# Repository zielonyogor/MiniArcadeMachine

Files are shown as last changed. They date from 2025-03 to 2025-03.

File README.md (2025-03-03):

# Mini-Arcade-Machine
Project made for Embedded Systems laboratories at Poznań University of Technology.

## General Information
This project is a miniature gaming machine inspired by arcade machines from the 1980s. It supports three types of logic games:
* Minesweeper, 
* Memory,
* Simon Says.  

The machine utilizes a Raspberry Pi 4B along with a PiTFT touchscreen. Case model was designed using FreeCAD and 3D-printed. It is controlled via a joystick and buttons. Additionally, a built-in buzzer produces sounds and plays melodies.  

For more information check out our (polish) [documentation](doc/project_report.pdf).

## Setup guide 

To setup the PiTFT display, refer to the official PiTFT [documentation](https://cdn-learn.adafruit.com/downloads/pdf/adafruit-pitft-28-inch-resistive-touchscreen-display-raspberry-pi.pdf).  
After that install pygame along with sdl library using the following command:

* *sudo apt install python3-pygame libsdl2-dev*

After successful installation run the program using:

* *sudo python main.py*

## Project presentation
To see our arcade machine in action look at the project showcase [video](doc/project_showcase.mp4).  

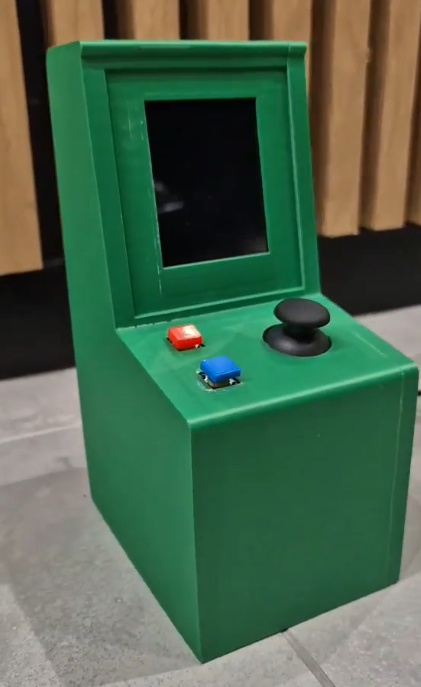
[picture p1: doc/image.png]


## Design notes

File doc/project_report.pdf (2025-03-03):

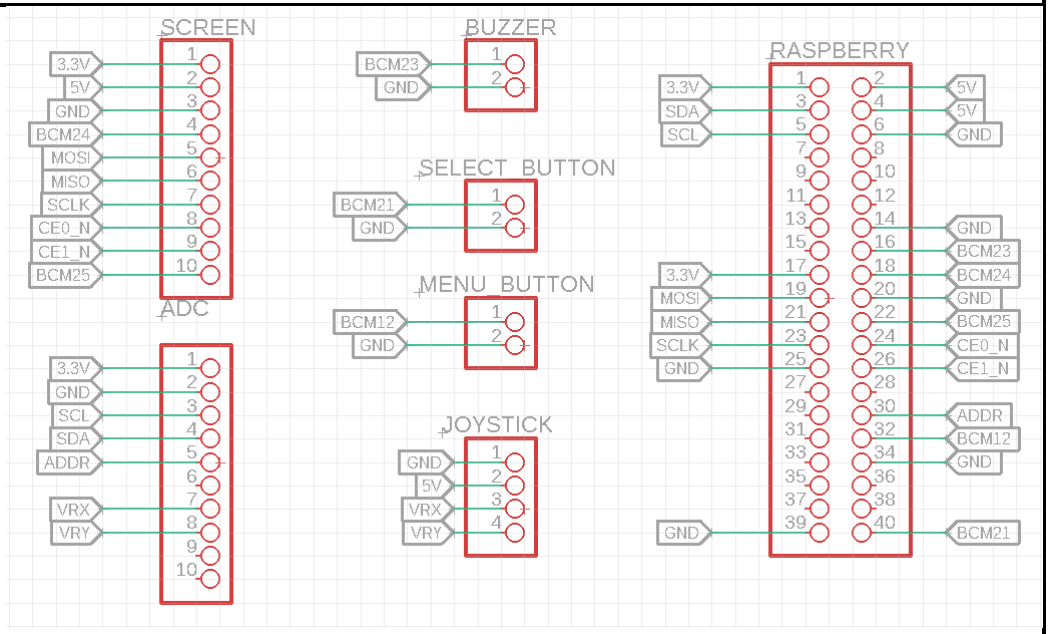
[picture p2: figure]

1

[Z7] KARTA PROJEKTU

Grupa laboratoryjna: L10/L4

Prowadzący zajęcia:

Mini Arcade Machine

CEL PROJEKTU

Stworzenie miniaturowej maszyny do gier inspirowanej maszynami arkadowymi z lat 80’. Maszyna posiada 3 rodzaje gier logicznych: Minesweeper, Memory oraz Simon Says. Model maszyny jest wydrukowany w drukarce 3D. Maszyna posiada joystick i 2 przyciski. Wbudowany jest również buzzer wydający efekty dźwiękowe oraz grający melodię.

SCHEMAT POGLĄDOWY (UPROSZCZONY)

WYKORZYSTANA
PLATFORMA
SPRZĘTOWA, ELEMENTY
POMIAROWE
I WYKONAWCZE

Raspberry Pi 4B, Thumb Joystick, przyciski Tact Switch, buzzer pasywny, wyświetlacz LCD TFT

2

1. Cel i zakres projektu.

Celem projektu było stworzenie miniaturowej maszyny do gier, inspirowanej maszynami arkadowymi z lat 80’. W wydrukowanej na drukarce 3D ‘maszynie’ znajduje się Raspberry Pi 4B, do której podłączone są urządzenia wyjścia oraz wejścia, takie jak: joystick, przyciski, buzzer, wyświetlacz. Całość zasilana jest za pomocą dedykowanego zasilacza USB C dla Raspberry Pi 4B.
Maszyna posiada 3 gry: „Minesweeper”, „Simon Says”, „Match-2” oraz tabele najlepszych wyników dla każdej z gier. Minesweeper, czyli saper to gra, której celem jest znalezienie bomb rozłożonych na planszy. Jako wskazówka, co do położenia bomb, reszta kafelek na planszy posiada liczbę, odpowiadającą liczbie bomb w sąsiedztwie danego kafelka. Im szybciej gracz odkryje wszystkie kafelki niezawierające bomb, tym lepszy wynik osiągnie. „Simon Says” to gra na czas, której celem jest odegranie melodii, naśladując podświetlone kafelki. Wynik liczony jest na podstawie ilości odegranych nut. „Match-2” to gra polegająca na zapamiętywaniu położenia kafelków odpowiedniego koloru oraz połączeniu dwóch kafelków o tych samych kolorach. Wynik jest liczony na podstawie czasu, ile graczowi zajęło połączenie wszystkich kolorów. Gry zostały napisane w języku programowania Python z użyciem biblioteki PyGame. PyGame jest prostą biblioteką stworzoną z myślą o tworzeniu gier w języku Python. Do przechowywania wyników użyliśmy bazy danych w SQLite. Pomimo małego rozmiaru przechowywanych wyników, zdecydowaliśmy się na użycie SQLite ze względu na prostotę zapytań i obsługi danych w porównaniu z tak zwaną „hardcodowaną” obsługą danych w pliku ‘txt’. Do interakcji z grą służą: joystick – do akcji „lewo”, „prawo”, „góra” i „dół” oraz dwa przyciski – niebieski – akcja „zatwierdź”, czerwony – akcja „menu”. Buzzer został wykorzystany jako informacja zwrotna dla gracza. W zależności od akcji, jaką gracz wykona, buzzer zagra krótką melodię: radosną, sugerującą wygraną grę lub smutną, sugerującą koniec gry. Dodatkowo buzzer reaguje krótkim dźwiękiem podczas wciskania przycisku interakcji.
Maszyna posiada w menu gry opcję bezpiecznego wyłączenia. Należy użyć tej opcji przed odłączeniem od zasilania, aby zabezpieczyć system przed korupcją plików.

Wykorzystany sprzęt:
- Raspberry Pi 4B 4GB RAM
- Wyświetlacz TFT 2.8”
- Thumb Joystick
- Konwerter ADC ADS1115
- Przyciski Tact Switch - x2
- Buzzer pasywny
- Zasilacz USB C 5.1V/3A do Raspberry Pi
- Przewody połączeniowe

Wykorzystane oprogramowanie:
- Visual Studio Code – programowanie i prototypowanie logiki gier
- PyCharm Proffesional Edition – komunikacja i przesyłanie oprogramowania do Raspberry Pi 4B
- FreeCAD – modelowanie 3D obudowy

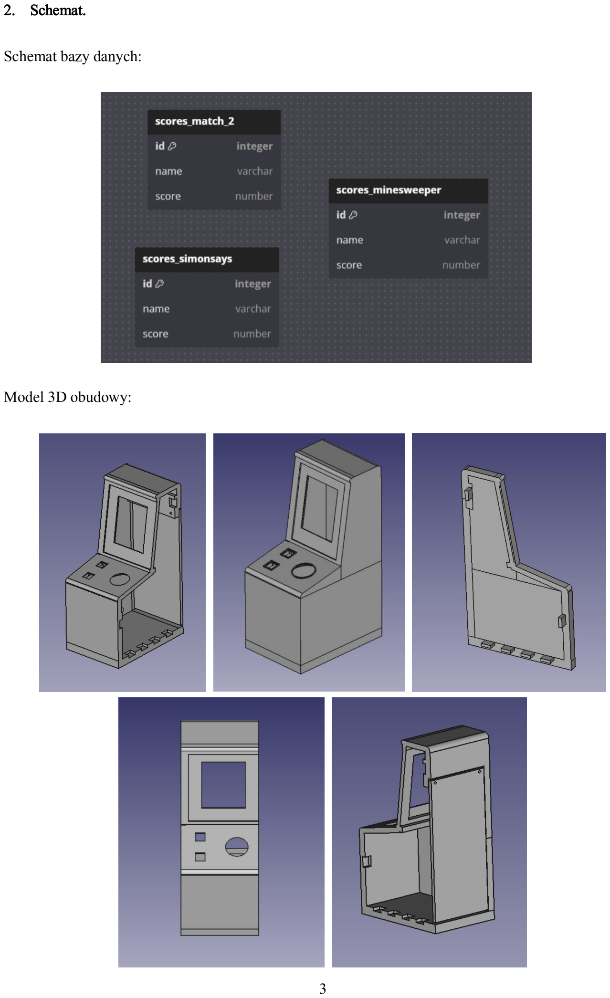
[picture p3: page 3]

3

2. Schemat.

Schemat bazy danych:

Model 3D obudowy:

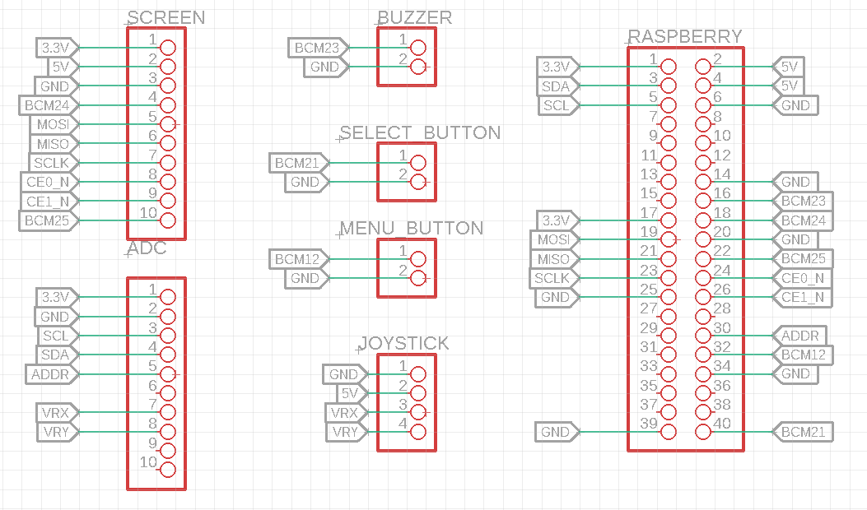
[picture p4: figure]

4

Schemat połączeniowy:

3. Zał oż enia projektowe a ich realizacja.

W założeniach projektowych planowaliśmy użyć przenośnego zasilania w postaci koszyka na akumulatory, jednakże ze względu na czas, jaki mogliśmy przeznaczyć na projekt oraz ryzyko jakie mogło nieść ze sobą zasilanie o niepewnym poziomie napięcia (ze względu na rozładowanie, np. możliwość błędnego odczytu wartości na joysticku przy operowaniu na niższym poziomie napięcia) postanowiliśmy stworzyć naszą maszynę bardziej zbliżoną oryginałom i uzależnić jej działanie od dostępu do gniazdka. Sprzęt zasilany jest poprzez dedykowaną do Raspberry Pi 4 ładowarkę USB-C.
Planowaliśmy również zaprojektować płytkę PCB do naszego projektu, jednak po dłuższym rozważeniu tej opcji uznaliśmy, że nie jest opłacalne poświęcać czas i pieniądze na dedykowaną płytkę, jako że cały nasz układ udało się połączyć zwykłymi przewodami z Raspberry Pi 4 w roli płytki PCB.
Projekt ma ogromne możliwości dalszego rozwoju. Nasz obecny projekt zajmuje niewielką frakcję obecnej pamięci, zostawiając sporo miejsca na możliwe przyszłe gry. Kombinacja joysticka i towarzyszących mu dwóch przycisków pozwala na przeróżne implementacje gier. Obecna implementacja reaguje wyłącznie na ruchy joysticka w kierunkach prawo/lewo/góra/dół. Można to zmienić w kodzie, aby pozwolić na odczyt pełnego zakresu ruchów joysticka, odkrywając nowe możliwe gry, czy techniki do wykorzystania w implementacji.

5

4. Listing kodu.

# Fragment pliku input.py zawierający obsługę urządzeń wejścia # (joystick, przyciski)

def setup():
# Inicjalizacja magistrali I2C

i2c = busio.I2C(board.SCL, board.SDA) # Inicjalizacja konwertera ADC
ads = ADS.ADS1115(i2c)

# Inicjalizacja przycisków menu i interakcji global select_button

global menu_button
select_button = Button(19, bounce_time=0.1)
menu_button = Button(26, bounce_time=0.1)

# Przypisanie zmiennej do pinów, z których odczytujemy wartość na joysticku global y_axis

global x_axis
y_axis = AnalogIn(ads, ADS.P0)
x_axis = AnalogIn(ads, ADS.P1)
# Zmienna, która zawiera zwracaną wartość z joysticka:

# NONE – joystick w stanie spoczynku

# LEFT, RIGHT, UP, DOWN (lewo, prawo, góra, dół)

# STANDBY – z joysticka została pobrana wartość, ale gracz nie sprowadził joysticka do stanu spoczynku

global joystick_value
joystick_value = NONE

# Pobór wartości z przycisków def get_button_input():

if select_button.is_pressed: return SELECT
if menu_button.is_pressed: return MENU
return NONE

# Fragment pliku buzzer.py zawierającego obsługę buzzera

# Zainicjalizowanie buzzera pasywnego na pinie 26

def setup():
global joystick_value
buzzer = TonalBuzzer(26)

6

# Szczęśliwa melodia. Grana, kiedy gracz wygra/wpisze swoje imię do tabeli # Kod polega na włączeniu buzzera na pewnym tonie, poczekaniu danego czasu # I na końcu wyłączeniu buzzera

def play_happy_melody():
buzzer.play(Tone('C5'))
sleep(0.1)
buzzer.play(Tone('E5'))
sleep(0.1)
buzzer.play(Tone('F5'))
sleep(0.5)
buzzer.stop()
return

# Fragment pliku database.py zawierającego obsługę bazy danych tj. tabeli wyników

# po uprzednim sprawdzeniu czy gracz osiągnął wynik godny tabeli i wpisaniu imienia przez gracza, ta funkcja zapisuje do tabeli match_2 wynik z gry Match-2 # data – tuple w formie (imie_gracza, wynik)

def add_match_2_score(data):
cursor.execute("SELECT COUNT(*) FROM match_2")
number_scores = cursor.fetchone()
cursor.execute("INSERT INTO match_2 (name, score) VALUES (?, ?)", (data[0], data[1]))

# limit najlepszych wyników to MAX_SCORES = 6

# jeśli już było 6 wyników to usunie ten najgorszy

if number_scores[0] >= MAX_SCORES:
cursor.execute("""DELETE FROM match_2 WHERE id = (select * from ( SELECT id FROM match_2 ORDER BY score ASC limit 6,1) AS t)""")
conn.commit()

# Plik game.py:

# klasa Game odpowiadająca za cały przebieg rozgrywki

class Game:
def __init__(self) -> None: os.environ["XDG_RUNTIME_DIR"] = "/tmp"
# inicjalizacja biblioteki PyGame i obsługi czcionek pygame.init()

pygame.font.init()

7

# Załadowanie ekranu, czcionki, zegara

self.screen = pygame.display.set_mode((SCREEN_WIDTH, SCREEN_WIDTH)) self.font = pygame.font.SysFont('arial', 24)
self.clock = pygame.time.Clock()

# GameStateManager – służy do obsługi zmiany scen

# (gry, tabela wyników, ekran wpisywania imienia, wybór gry) self.game_state_manager = GameStatemanager('select') self.game_state_manager.setup(self)

self.is_running = True
# Inicjalizacja scen

self.scenes = {'select': SelectScene(self.screen, self.game_state_manager, self.font), 'match2': Match2(self.screen, self.game_state_manager, self.font),
'simonsays': SimonSays(self.screen, self.game_state_manager, self.font), 'minesweeper': MinesweeperScene(self.screen, self.game_state_manager, self.font), 'leaderboard': LeaderboardScene(self.screen, self.game_state_manager, self.font), 'entername': EnterNameScene(self.screen, self.game_state_manager, self.font)}

def run(self):
while self.is_running:
# Zaktualizuj wartość pobieraną z joysticka input.update_joystick()

# Jeśli gracz kliknie przycisk MENU i nie znajduje się # w scenie wyboru gier to przenieś go do wyboru gier if input.get_button_input() == input.MENU and self.game_state_manager.get_state() != 'select': self.game_state_manager.change_state('select')

else:
# Zaktualizuj input w danej scenie self.scenes[self.game_state_manager.get_state()].update()

# Wyświetl obecną scenę

self.scenes[self.game_state_manager.get_state()].run() pygame.display.update()
# Ogranicz ilość FPS (klatek na sekundę) self.clock.tick(FPS)

# Plik match2.py – wyświetlanie i logika gry Match-2

8

class Match2(Scene):
def __init__(self, display, game_state_manager, font) -> None: super().__init__(display, game_state_manager, font)

self.time_text = self.font.render('Time: 0000', False, (255, 255, 255))

# Dostępne kolory w grze, skopiowane dwa razy (para o takim samym kolorze)

colors = ["#66CCFF", "#F2973D", "#FF0000", "#FF99FF", "#330066", "#0242BA", "#66FF66", "#FFFF57"] self.colors = colors + colors

# Wskaźnik na pole, na którym jest gracz

self.pointer = fig.Pointer(SQUARE_SIZE, ROWS, COLUMNS)

# Funkcja wywoływana przy zmianie scen

def enter(self):
self.remaining = COLUMNS * ROWS / 2 # ile par zostało do odkrycia

shuffle(self.colors) # pomieszanie kolorów
# Dostępne kolory przedstawione jako macierz COLUMNS * ROWS self.available_colors = [self.colors[i * COLUMNS:(i + 1) * COLUMNS] for i in range(ROWS)]

self.squares = []
# Zakrycie kwadratów, których nie odkryliśmy

self.placeholder = fig.Square(0, 0, SQUARE_SIZE, '#757575')
# 0 - nic, 1 – zaznaczony, 2 - odkryty

self.squares_state = [[0 for _ in range(COLUMNS)] for _ in range(ROWS)]

# Wypełnienie macierzy kwadratami z odpowiednimi kolorami

for i in range(ROWS):
y = i * (SQUARE_SIZE + 12) + 36
l = []
for j in range(COLUMNS):
x = j * (SQUARE_SIZE + 12) + OFFSET_X square = fig.Square(x, y, SQUARE_SIZE, self.available_colors[i][j]) l.append(square)
self.squares.append(l)

# Przygotowanie zmiennych czasowych self.state_time = time.time() self.start_time = 0

self.current_time = 0

9

self.state = 'show_all' # show-all – pokaż pary na starcie # game - rozgrywka
# show – pokaż odkrytą parę

self.selected = None

# Obsługa inputu

def update(self):
if self.state != 'game':
return
# Przesuń wskaźnik

joystick = input.get_joystick_input() if joystick == input.LEFT: self.pointer.move(-1, 0)
elif joystick == input.RIGHT: self.pointer.move(1, 0)
elif joystick == input.UP: self.pointer.move(0, -1)
elif joystick == input.DOWN:
self.pointer.move(0, 1)
elif input.get_button_input() == input.SELECT:
# Krótka melodia reakcji na kliknięcie kwadratu

music_thread = threading.Thread(target=buzzer.play_select_melody, daemon=True)
music_thread.start()

# Sprawdzanie czy para jaką gracz zaznaczył jest dobra current_row = self.pointer.current_index[0] current_col = self.pointer.current_index[1] if(self.squares_state[current_row][current_col] == 0): self.squares_state[current_row][current_col] = 1

if(self.selected != None):

current_color =
self.available_colors[current_row][current_col]

prev_square_color =
self.available_colors[self.selected[0]][self.selected[1]] if(current_color == prev_square_color):
# Ustawienie kwadratów na ‘odkryte’ self.squares_state[current_row][current_col] = 2 self.squares_state[self.selected[0]][self.selected[1]] = 2

self.remaining -= 1 # Odkryto pare
else:

10

self.squares_state[current_row][current_col] = 0 self.squares_state[self.selected[0]][self.selected[1]] = 0

self.state_time = time.time()
self.state = 'show'
else:
self.selected = (current_row, current_col)

elif(self.squares_state[current_row][current_col] == 1): print('unselecting')
self.selected = None
self.squares_state[current_row][current_col] = 0 def run(self):
match self.state:
case 'show_all':
self.update_show_all()
case 'game':
self.update_game()
case 'show':
self.update_show()
case _:
pass

# Pokazanie na starcie jak wygląda plansza

def update_show_all(self):
if time.time() - self.state_time > SHOW_ALL_TIME: self.state = 'game'
self.start_time = time.time()
return

self.display.fill(pygame.Color('black'))

for i in range(ROWS):
for j in range(COLUMNS):
self.display.blit(self.squares[i][j].surf, self.squares[i][j])

# Widok gry

def update_game(self):
self.display.fill(pygame.Color('black'))

for i in range(ROWS):
y = i * (SQUARE_SIZE + 12) + 36
for j in range(COLUMNS):
x = j * (SQUARE_SIZE + 12) + OFFSET_X if(self.squares_state[i][j] == 0): # Zakryte – szary kwadrat

11

self.display.blit(self.placeholder.surf, (x, y)) elif(self.squares_state[i][j] == 1): # Zaznaczone, pokaż kolor self.display.blit(self.squares[i][j].surf, self.squares[i][j])

self.update_time()
self.display.blit(self.time_text, (60, 2))

pygame.draw.rect(self.display, pygame.Color('white'), self.pointer.rect, 4)

# Jeśli gracz zaznaczy parę kwadratów, pokaż przez chwilę te kwadraty

def update_show(self):
if time.time() - self.state_time > SHOW_TIME:
self.selected = None

# Jeśli to była ostatnia para:

# - puść melodię wygranej,

# - sprawdź czy gracz dostał się do najlepszych wyników,

# - przenieś gracza do menu głównego lub do sceny wprowadzania imienia do tabeli,

if self.remaining == 0:
music_thread = threading.Thread(target=buzzer.play_happy_melody, daemon=True)
music_thread.start()
if db.is_better_match_2(self.current_time): self.game_state_manager.enter_name_scene('match_2', self.current_time)
return

self.game_state_manager.change_state('select') return

self.state = 'game'
return

self.display.fill(pygame.Color('black'))

for i in range(ROWS):
y = i * (SQUARE_SIZE + 12) + 36
for j in range(COLUMNS):
x = j * (SQUARE_SIZE + 12) + OFFSET_X
# Wyświetl zaznaczoną parę

if ((i, j) == self.selected) or ([i, j] == self.pointer.current_index):

12

self.display.blit(self.squares[i][j].surf, self.squares[i][j])
elif (self.squares_state[i][j] == 0): self.display.blit(self.placeholder.surf, (x, y))

self.update_time()
self.display.blit(self.time_text, (120 - self.time_text.get_width() // 2, 2))

# Aktualizacja czau i jego tekstu

def update_time(self):
self.current_time = time.time() - self.start_time

temp_string = f'{self.current_time:.1f}'.zfill(6)
self.time_text = self.font.render(f'Time: {temp_string}', False, (255, 255, 255))

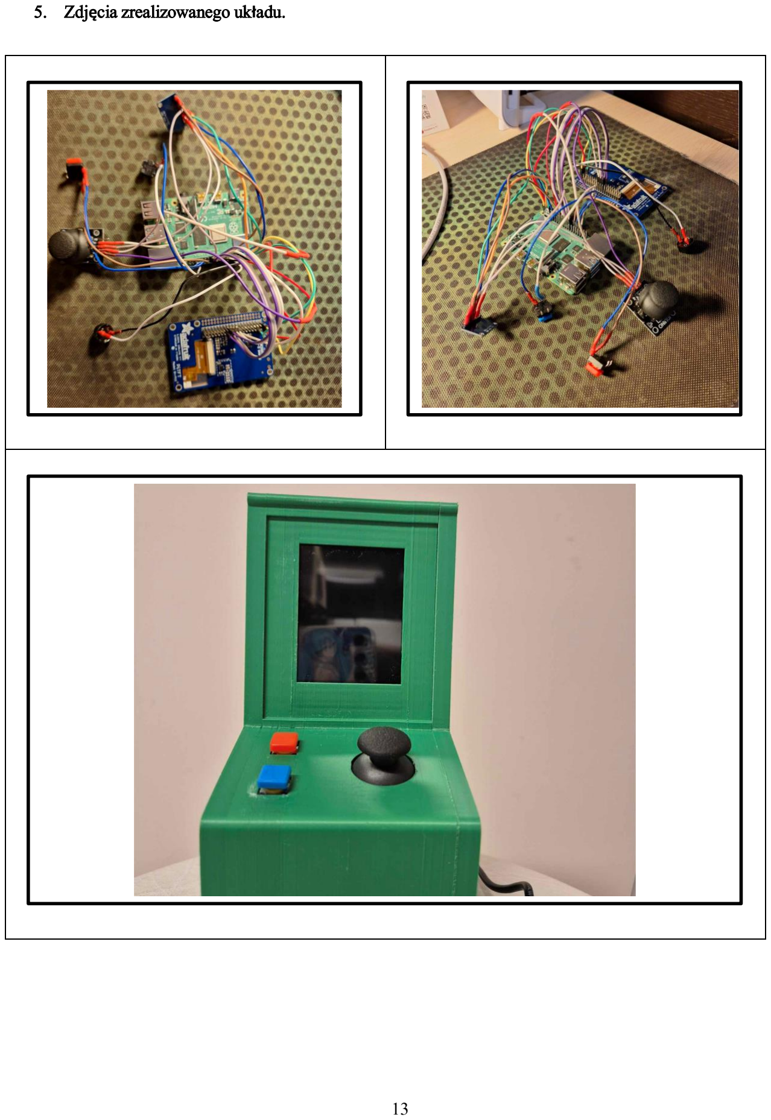
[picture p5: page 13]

13

5. Zdjęcia zrealizowanego układu.

14

6. Podsumowanie i wnioski.
Nasz projekt zakończył się sukcesem. Połączyliśmy temat zastosowania podstaw systemów wbudowanych z naszą pasją do gier. Udało nam się osiągnąć oczekiwany efekt, zarówno pod kątem estetycznym jak i kątem programistycznym. Gry sprawiają przyjemność podczas grania, brak błędów psujących rozgrywkę. Wygląd gier jest prosty, ale i intuicyjny. Kod jest czytelny. Architektura programu jest łatwa do zrozumienia i rozszerzenia o większą ilość gier. Program działa płynnie i bez problemów. Obudowa jest estetyczna i odzwierciedla wygląd oryginalnych maszyn arkadowych.
Poznaliśmy różne formy komunikacji pomiędzy sprzętami. Do komunikacji komputera z Raspberry Pi używaliśmy protokołu SSH w celu wysyłania komend oraz protokołu SMTP do edytowania i przesyłania plików. W naszym projekcie wykorzystaliśmy urządzenia takie jak analogowy joystick i wyświetlacz. Wyświetlacz działa na interfejsie urządzeń peryferyjnych (SPI). Joystick natomiast najpierw przesyła sygnał do konwertera sygnału analogowego na cyfrowy (ADC), a następnie konwerter łączy się z Raspberry Pi na magistrali I2C. Nasz projekt wykorzystuje również proste urządzenia wejścia, tj. przyciski Tact switch, oraz proste urządzenia wyjścia, tj. buzzer pasywny.
Biblioteka PyGame świetnie się sprawdziła w naszym projekcie. Jej prostota pozwalała na szybką i schludną implementację gier. Mogliśmy również testować oprogramowanie uprzednio na komputerze, a następnie przetłumaczyć logikę klawiszy komputerowych na logikę wejść w urządzeniu.
Wyzwaniem dla nas był projekt od strony sprzętowej. To było nasze pierwsze doświadczenie z Raspberry Pi, więc na bieżąco musieliśmy aktualizować naszą wiedzę na temat tego mini komputera. Trudnym zadaniem też było poprawne podłączenie wyświetlacza do Raspberry Pi. Informacje w internecie na temat naszego wyświetlacza były znikome lub nieaktualne.

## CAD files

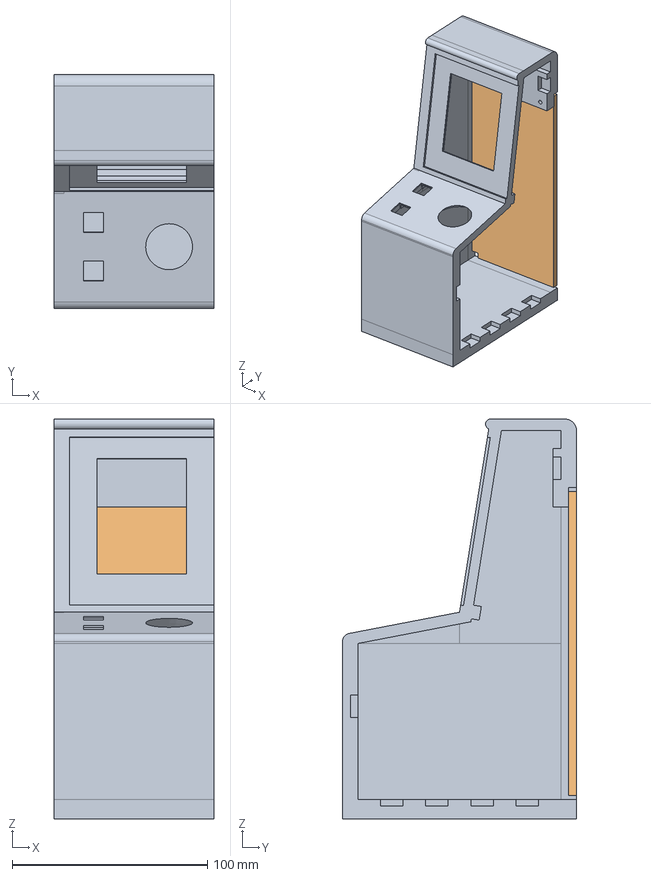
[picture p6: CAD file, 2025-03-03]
model/base.FCStd
82.0 x 120.0 x 205.1 mm
Door

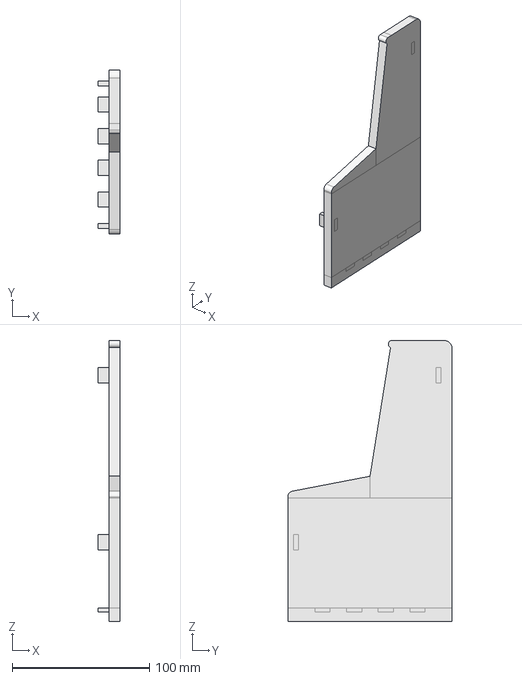
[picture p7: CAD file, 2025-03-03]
model/wall.FCStd
15.8 x 120.0 x 205.1 mm

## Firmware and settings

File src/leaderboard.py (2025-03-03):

import pygame
from pygame.locals import *
from game_scene import Scene

import database as db
import input

import buzzer
import threading

ICON_SIZE = 64

class Place():
    def __init__(self, x, y, font, data = [0, '.......................', '000']):
        self.font = font
        self.text_nr = font.render(str(data[0]), False, (255, 255, 255))
        self.text_name = font.render(data[1], False, (255, 255, 255))
        self.text_score = font.render(str(data[2]), False, (255, 255, 255))
        self.dest = (x, y)
    
    def change_text(self, new_data):
        self.text_nr = self.font.render(str(new_data[0]), False, (255, 255, 255))
        self.text_name = self.font.render(new_data[1], False, (255, 255, 255))
        self.text_score = self.font.render(str(new_data[2]), False, (255, 255, 255))
    
class LeaderboardScene(Scene):
    def __init__(self, display, game_state_manager, font):
        super().__init__(display, game_state_manager, font)
        
        self.texts = [self.font.render('MATCH-2', False, (255, 255, 255)),
                      self.font.render('SIMONSAYS', False, (255, 255, 255)),
                      self.font.render('MINESWEEPER', False, (255, 255, 255))]
        
        self.match_leaderboards = []
        self.simonsays_leaderboards = []
        self.minesweeper_leaderboards = []

        for i in range(6):
            match_score = Place(10, 58 + 28 * i, font)
            self.match_leaderboards.append(match_score)

            simon_says = Place(10, 58 + 28 * i, font)
            self.simonsays_leaderboards.append(simon_says)
            
            minesweeper_score = Place(10, 58 + 28 * i, font)
            self.minesweeper_leaderboards.append(minesweeper_score)

        self.current_index = 1

        db.init()
    
    def enter(self):    
        self.current_index = 1
    
        match2_scores = db.get_match_2_scores()
        simonsays_scores = db.get_simon_says_scores()
        minesweeper_scores = db.get_minesweeper_scores()
        for i in range(len(match2_scores)):
            self.match_leaderboards[i].change_text(match2_scores[i])
        for i in range(len(simonsays_scores)):
            self.simonsays_leaderboards[i].change_text(simonsays_scores[i])
        for i in range(len(minesweeper_scores)):
            self.minesweeper_leaderboards[i].change_text(minesweeper_scores[i])
        self.was_updated = True

    def update(self):
        joystick = input.get_joystick_input()
        if joystick == input.LEFT:
            music_thread = threading.Thread(target=buzzer.play_select_melody, daemon=True)
            music_thread.start()
            self.current_index = (self.current_index - 1) % 3
            self.was_updated = True
        elif joystick == input.RIGHT:
            music_thread = threading.Thread(target=buzzer.play_select_melody, daemon=True)
            music_thread.start()
            self.current_index = (self.current_index + 1) % 3
            self.was_updated = True

    def run(self):
        # self.update_screen()
        if self.was_updated == True:
            self.was_updated = False
            self.update_screen()
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

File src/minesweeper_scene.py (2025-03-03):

import pygame
from pygame.locals import *

import figures as fig
from globals import *
from game_scene import Scene
import time
import random
import database as db

import input
import buzzer
import threading

SQUARE_SIZE = 18
ROWS = 9
COLUMNS = 9

class MinesweeperScene(Scene):
    def __init__(self, display, game_state_manager, font) -> None:

        super().__init__(display, game_state_manager, font)

        self.time_text = self.font.render('Time: 0000', False, (255, 255, 255))

        self.pointer = fig.Pointer(SQUARE_SIZE, ROWS, COLUMNS, 24, 36, 4)
        self.square_icon = fig.Square(0, 0, SQUARE_SIZE, '#CCCCCC')


        self.number_font = pygame.font.SysFont('arial', 20, bold=True)
        self.text_numbers = []

        texts_and_colors = [
            ('B', (255, 0, 0)),
            ('1', (0, 0, 255)),
            ('2', (0, 255, 0)),
            ('3', (255, 0, 0)),
            ('4', (94, 23, 176)),
            ('5', (140, 10, 55)),
            ('6', (10, 191, 158)),
            ('7', (0, 0, 0)),
            ('8', (137, 138, 102))
        ]

        for text, color in texts_and_colors:
            surface = pygame.Surface((SQUARE_SIZE, SQUARE_SIZE), pygame.SRCALPHA)
            rendered_text = self.number_font.render(text, True, color)
            text_rect = rendered_text.get_rect(center=(SQUARE_SIZE // 2, SQUARE_SIZE // 2))
            surface.blit(rendered_text, text_rect)
            self.text_numbers.append(surface)

        self.placeholder = fig.Square(0, 0, SQUARE_SIZE, '#757575')

    def enter(self):
        self.bombs = self.randomize_bombs()
        self.find_numbers()
        self.squares_state = [[0 for _ in range(COLUMNS)] for _ in range(ROWS)] # 0 - hidden, 1 - shown

        self.current_time = 0
        self.start_time = time.time()
        self.found = 0

        self.is_over = False
        self.won = False

    def update(self):
        if self.is_over:
            if input.get_button_input() == input.SELECT:
                if not self.won:
                    self.game_state_manager.change_state('select')
                    return
                if db.is_better_minesweeper(self.current_time):
                    self.game_state_manager.enter_name_scene('minesweeper', self.current_time)
                else:
                    self.game_state_manager.change_state('select')
            return

        joystick = input.get_joystick_input()
        if joystick == input.LEFT:
            self.pointer.move(-1, 0)
        elif joystick == input.RIGHT:
            self.pointer.move(1, 0)
        elif joystick == input.UP:
            self.pointer.move(0, -1)
        elif joystick == input.DOWN:
            self.pointer.move(0, 1)
        elif input.get_button_input() == input.SELECT:
            row = self.pointer.current_index[0]
            column = self.pointer.current_index[1]
            if self.squares_state[row][column] == 1:
                return
            if self.square_numbers[row][column] == -1:
                music_thread = threading.Thread(target=buzzer.play_sad_melody, daemon=True)
                music_thread.start()
                print('Game Over')
                self.show_end()
                return
            if self.square_numbers[row][column] == 0:
                self.reveal_connected_zeros(row, column)
                music_thread = threading.Thread(target=buzzer.play_select_melody, daemon=True)
                music_thread.start()
            else:
                self.squares_state[row][column] = 1
                music_thread = threading.Thread(target=buzzer.play_select_melody, daemon=True)
                music_thread.start()
                self.found += 1

            if self.found == ROWS * COLUMNS - 10:
                music_thread = threading.Thread(target=buzzer.play_happy_melody, daemon=True)
                music_thread.start()
                print('Wygrana')
                self.won = True
                self.show_end()

    def run(self):
        if self.is_over:
            return

        self.display.fill(pygame.Color('black'))

        for i in range(ROWS):
            for j in range(COLUMNS):
                y = i * (SQUARE_SIZE + 4) + 36
                x = j * (SQUARE_SIZE + 4) + 24
                if self.squares_state[i][j] == 1:
                    self.display.blit(self.square_icon.surf,  (x, y))
                    if self.square_numbers[i][j] > 0:
                        self.display.blit(self.text_numbers[self.square_numbers[i][j]], (x, y))
                else:
                    self.display.blit(self.placeholder.surf, (x, y))

        pygame.draw.rect(self.display, pygame.Color('white'), self.pointer.rect, 4)

        self.update_time()
        self.display.blit(self.time_text, (120 - self.time_text.get_width() // 2, 2))

        pygame.display.update()

    def update_time(self):
        self.current_time = time.time() - self.start_time

        temp_string = f'{self.current_time:.1f}'.zfill(6)
        self.time_text = self.font.render(f'Time: {temp_string}', False, (255, 255, 255))

    def show_end(self):
        self.is_over = True

        self.display.fill(pygame.Color('black'))

        for i in range(ROWS):
            for j in range(COLUMNS):
                y = i * (SQUARE_SIZE + 4) + 36
                x = j * (SQUARE_SIZE + 4) + 24
                self.display.blit(self.square_icon.surf,  (x, y))
                if self.square_numbers[i][j] > 0:
                    self.display.blit(self.text_numbers[self.square_numbers[i][j]], (x, y))
                elif self.square_numbers[i][j] == -1:
                    self.display.blit(self.text_numbers[0], (x, y))

        self.display.blit(self.time_text, (60, 2))

        pygame.display.update()

    # algorithm related methods
    def randomize_bombs(self):
        bombs = [-1, -1, -1, -1, -1, -1, -1, -1, -1, -1]
        for i in range(10):
            number = random.randrange(0, ROWS*COLUMNS)
            while number in bombs:
                number = random.randrange(0, ROWS*COLUMNS)
            print(number)
            bombs[i] = number
        return bombs

    def find_numbers(self):
        self.square_numbers = [[0 for _ in range(COLUMNS)] for _ in range(ROWS)]
        for b in self.bombs:
            y = b // ROWS
            x = b % COLUMNS
            self.square_numbers[y][x] = -1

        def is_valid(row, col):
            return 0 <= row < ROWS and 0 <= col < COLUMNS

        directions = [
            (-1, -1), (-1, 0), (-1, 1),  # top-left, top, top-right
            (0, -1),         (0, 1),     # left,        right
            (1, -1), (1, 0), (1, 1)      # bottom-left, bottom, bottom-right
        ]
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

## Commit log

2024-12-16 First Raspberry Pi code
2024-12-18 Minesweeper time position fix
    [minesweeper_scene.py]
2024-12-20 Fix letter change in enter_name, centered text
    [enter_name.py, figures.py, leaderboard.py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]
2025-03-03 Add project documentation
    [base.FCStd, wall.FCStd]
